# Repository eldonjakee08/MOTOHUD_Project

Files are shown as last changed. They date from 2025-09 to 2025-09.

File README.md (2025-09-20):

# MotoHUD Project
A proof of concept project that aims to integrate a heads-up display (HUD) into a motorcycle helmet, projecting real-time ECU sensor data such as speed, RPM, and engine load directly into the rider’s field of view.

This project aims to enhance riders situational awareness and safety by delivering vehicle metrics without requiring the rider to look away from the road.

# System Architecture & Overview


<br>**TRANSMITTER**
1. STM32WB5MMG MCU wakes up every 100ms to poll the motorcycle CAN bus for ECU sensor data.(e.g. Speed, RPM, Engine Load, etc.) 
2. Transmitter sends the ECU sensor data via BLE.
3. MCU goes into deep sleep state to conserve power. 

<br>**RECEIVER**
1. STM32WB5MMG MCU wakes up from deep sleep upon reception of sensor data from transmitter
2. MCU Parses the received data and displays into OLED screen.
3. Beamsplitter glass reflects the projection from OLED screen into the riders field of view
4. MCU returns into deep sleep state to conserve power.

# Project Milestones & Progress
1. Designed and fabricated a custom development board for STM32WB5MMG MCU.
2. Designed and fabricated custom module for LM3671 to power the receiver.
3. Designed the initial hardware for both Receiver and Transmitter.
4. Developed custom driver for SSD1315 OLED driver.
5. On-going development of custom driver for MCP2515 CAN controller

# Pending Tasks
1. Develop application firmware for both receiver and transmitter.
2. Fabricate the hardware for both receiver and transmitter.
3. Design and fabricate a receiver enclosure for optimal mounting into the helmet.
4. Design and fabricate an enclosure for the transmitter.

 # Future Improvements & Optimizations
 1. Optimize I2C and SPI data transmission using Direct Memory Access (DMA) to achieve higher throughput and lower power consumption.
 2. Design a load sharing protection circuit for the receiver’s battery to support simultaneous operation and charging.
 3. Music streaming feature via Bluetooth Low Energy (BLE).
 4. END VISION: Seamlessly stream live ECU sensor data into the helmets visor, delivering a real-time Augmented Reality (AR) experience.

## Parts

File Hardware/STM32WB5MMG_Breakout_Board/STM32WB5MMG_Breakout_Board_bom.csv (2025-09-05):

Comment | Designator | Footprint
100nF | C1 | Capacitor_SMD:C_0603_1608Metric
3.3pF | C2,C4 | Capacitor_SMD:C_0201_0603Metric
4.7uF | C5 | Capacitor_SMD:C_0603_1608Metric
Conn_01x15_Pin | J1,J4 | Connector_PinHeader_2.54mm:PinHeader_1x15_P2.54mm_Vertical
Conn_01x11_Pin | J2 | Connector_PinHeader_2.54mm:PinHeader_1x11_P2.54mm_Vertical
Conn_01x10_Pin | J3 | Connector_PinHeader_2.54mm:PinHeader_1x10_P2.54mm_Vertical
Conn_01x05_Pin | J5 | Connector_PinHeader_2.54mm:PinHeader_1x05_P2.54mm_Vertical
Conn_01x2_Pin | J6 | Connector_PinHeader_2.54mm:PinHeader_1x02_P2.54mm_Vertical
Conn_01x1_Pin | J7 | Connector_PinHeader_2.54mm:PinHeader_1x01_P2.54mm_Vertical
100 Ohms | R1 | Resistor_SMD:R_0201_0603Metric
STM32WB5MMG | U1 | RF_Module:ST-SiP-LGA-86-11x7.3mm

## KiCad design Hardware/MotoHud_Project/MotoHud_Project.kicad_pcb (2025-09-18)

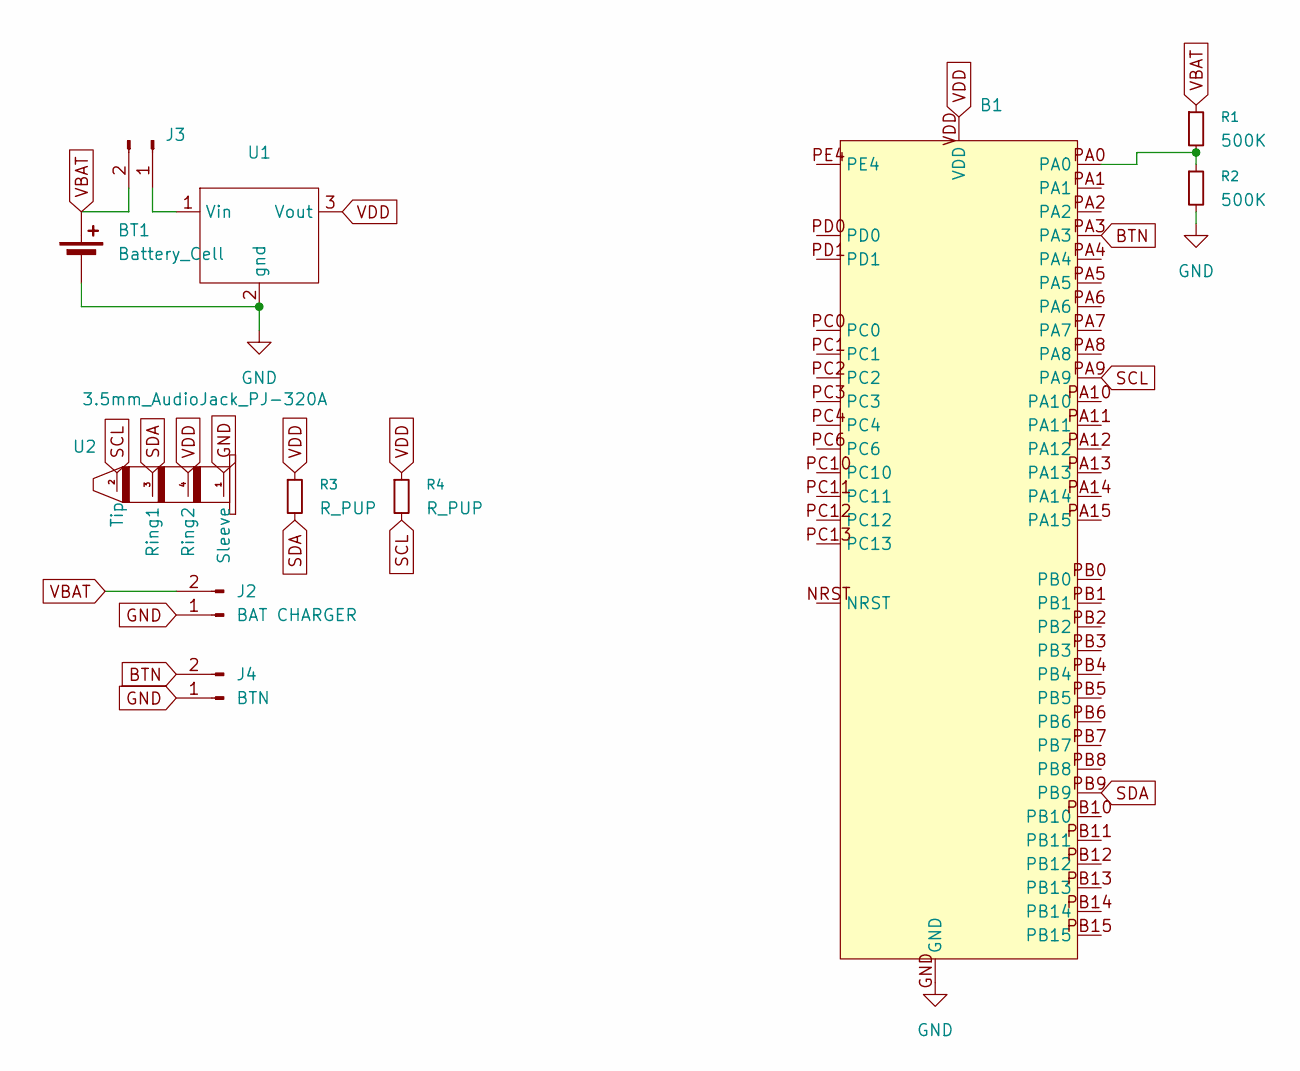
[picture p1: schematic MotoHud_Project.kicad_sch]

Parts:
B1: STM32WB5MMG_CUSTOM_DEVBOARD
BT1: Battery_Cell; PinHeader_1x02_P2.54mm_Vertical
J2: BAT CHARGER; PinHeader_1x02_P2.54mm_Vertical
J3: Conn_01x02_Pin; PinHeader_1x02_P2.54mm_Vertical
J4: BTN; PinHeader_1x02_P2.54mm_Vertical
R1, R2: 500K; R_0603_1608Metric_Pad0.98x0.95mm_HandSolder
R3, R4: R_PUP; R_Axial_DIN0207_L6.3mm_D2.5mm_P10.16mm_Horizontal
U1: LM3671_MODULE
U2: 3.5mm_AudioJack_PJ-320A; 3.5mm_AudioJack_PJ-320A_NoGuide

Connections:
BTN: B1.PA3, J4.2
GND: B1.GND, BT1.2 (-), J2.1, J4.1, R2.2, U1.2 (gnd), U2.1 (Sleeve)
unnamed: B1.PA0, R1.2, R2.1
unnamed: J3.1, U1.1 (Vin)
SCL: B1.PA9, R4.2, U2.2 (Tip)
SDA: B1.PB9, R3.2, U2.3 (Ring1)
VBAT: BT1.1 (+), J2.2, J3.2, R1.1
VDD: B1.VDD, R3.1, R4.1, U1.3 (Vout), U2.4 (Ring2)

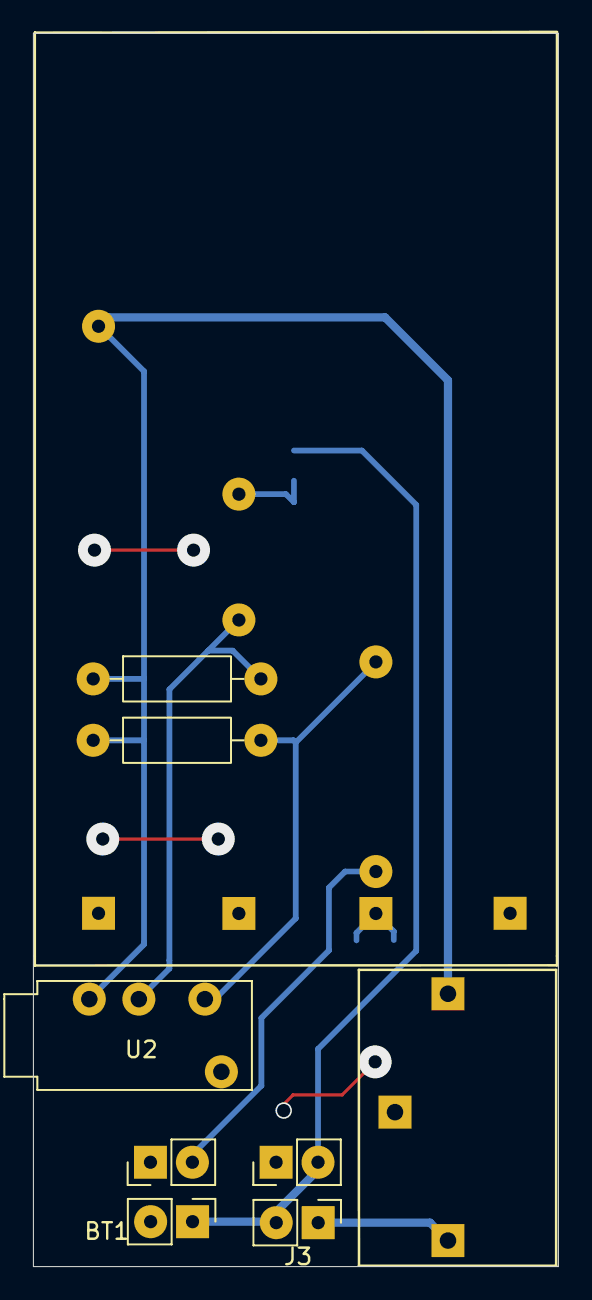
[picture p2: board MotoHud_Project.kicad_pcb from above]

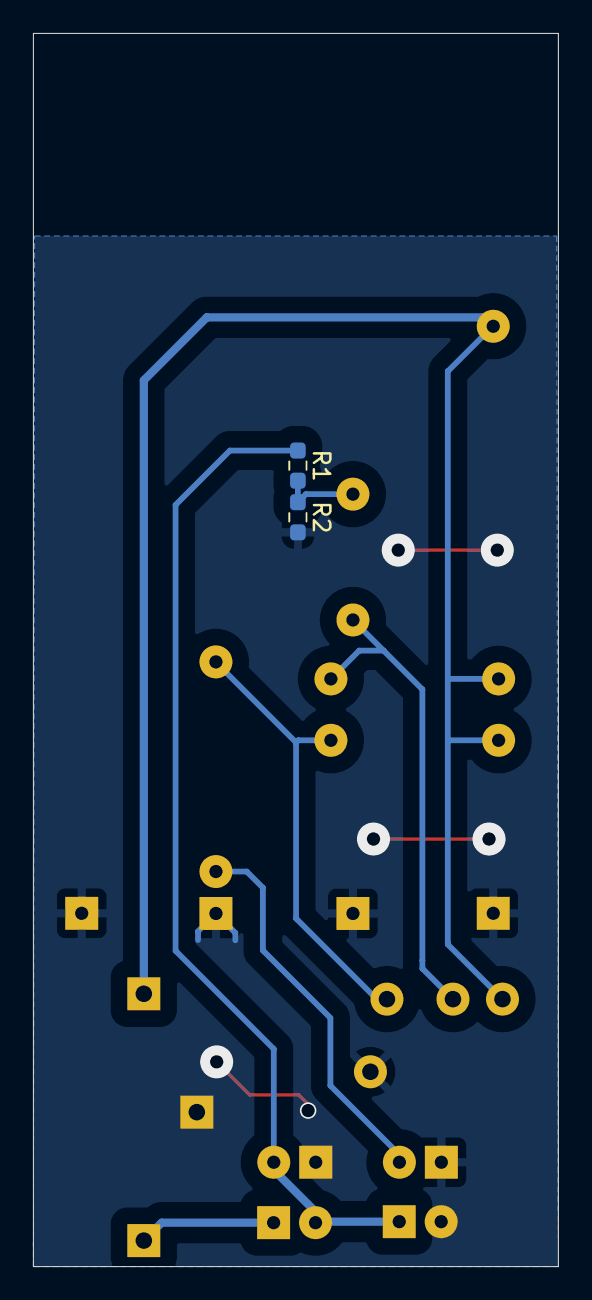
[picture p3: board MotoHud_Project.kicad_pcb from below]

Board: 2 copper layers, 31.8 x 74.7 mm, 11 parts (2 on the bottom side), 8 nets.

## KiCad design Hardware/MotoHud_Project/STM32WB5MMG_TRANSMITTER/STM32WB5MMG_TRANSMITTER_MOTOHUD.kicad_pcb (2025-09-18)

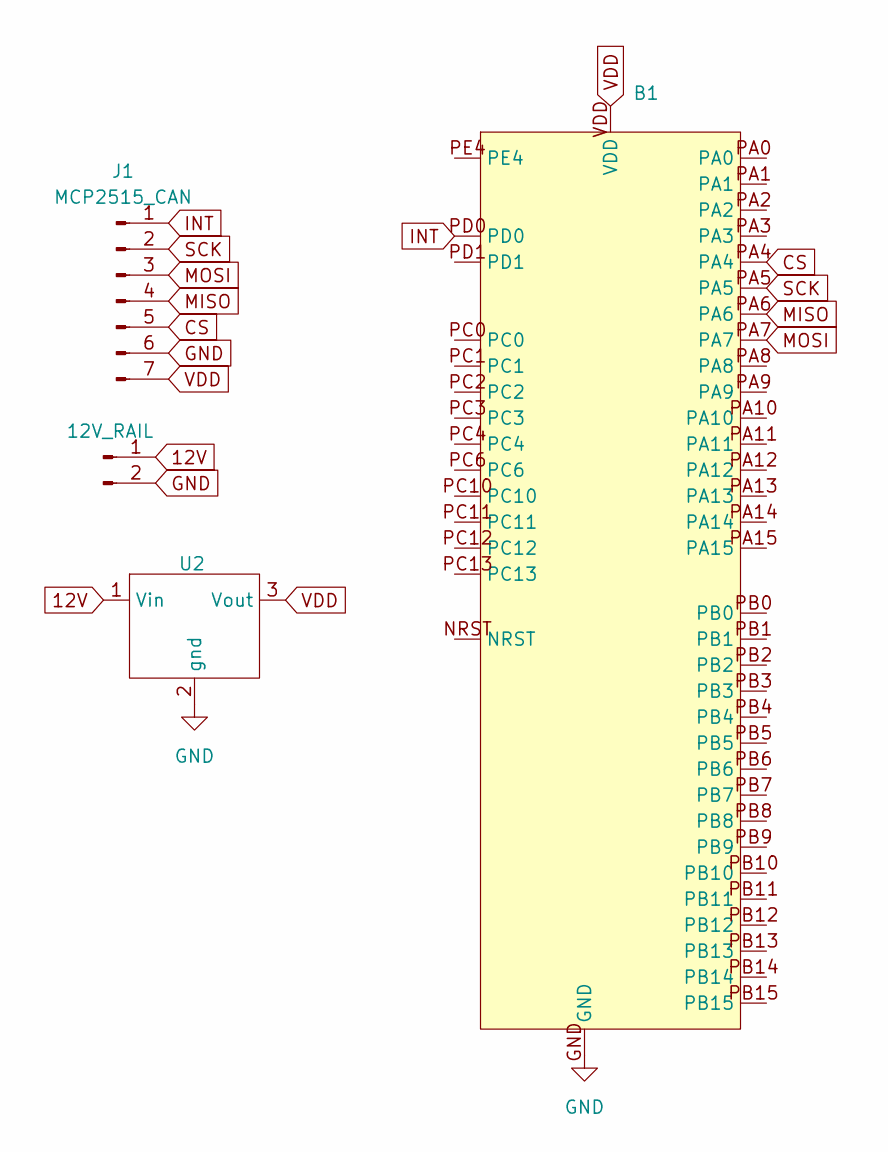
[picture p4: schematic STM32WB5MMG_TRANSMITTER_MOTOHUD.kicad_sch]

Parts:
B1: STM32WB5MMG_CUSTOM_DEVBOARD
J1: MCP2515_CAN; MCP2515_MODULE
J3: 12V_RAIL; PinHeader_1x02_P2.54mm_Vertical
U2: MP1584EN_DCtoDC_REGULATOR

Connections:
12V: J3.1, U2.1 (Vin)
CS: B1.PA4, J1.5
GND: B1.GND, J1.6, J3.2, U2.2 (gnd)
INT: B1.PD0, J1.1
MISO: B1.PA6, J1.4
MOSI: B1.PA7, J1.3
SCK: B1.PA5, J1.2
VDD: B1.VDD, J1.7, U2.3 (Vout)

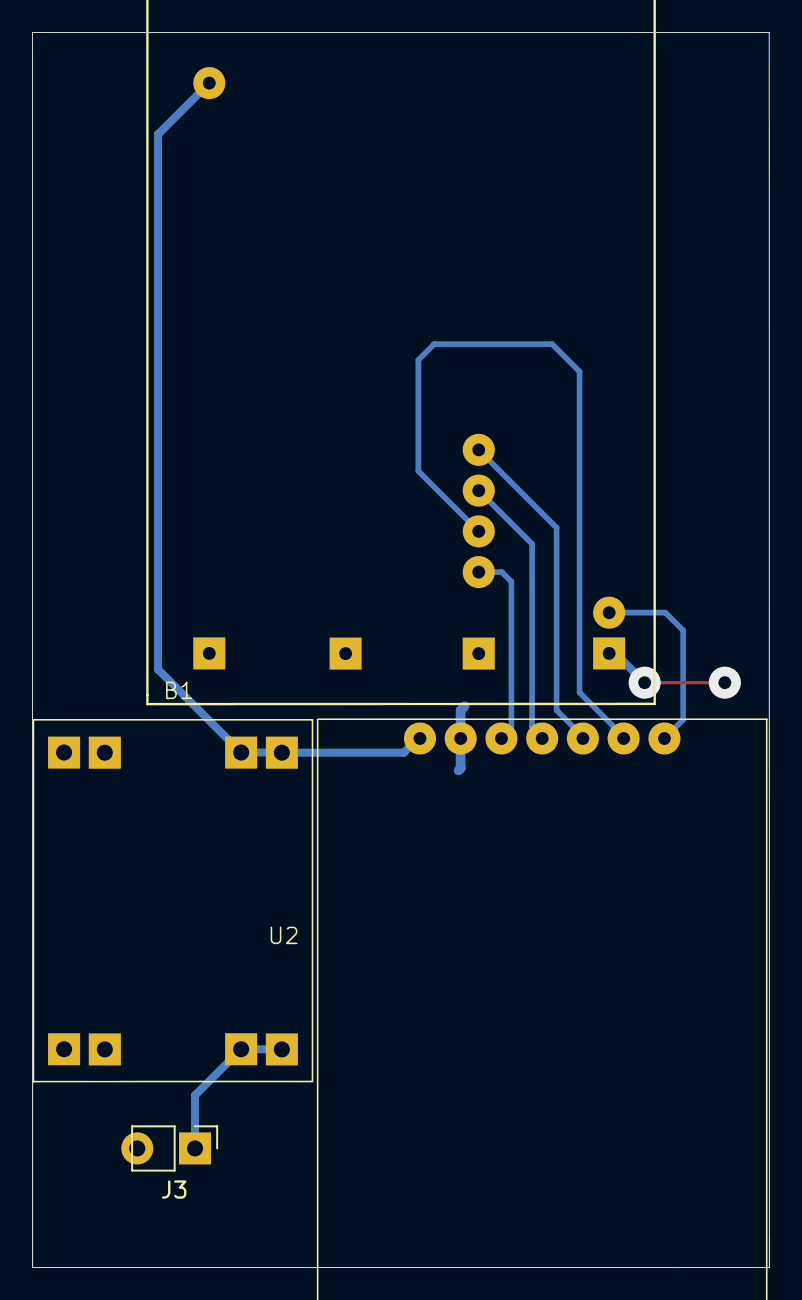
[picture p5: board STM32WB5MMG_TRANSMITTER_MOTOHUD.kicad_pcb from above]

Board: 2 copper layers, 46.0 x 77.0 mm, 4 parts (0 on the bottom side), 8 nets.

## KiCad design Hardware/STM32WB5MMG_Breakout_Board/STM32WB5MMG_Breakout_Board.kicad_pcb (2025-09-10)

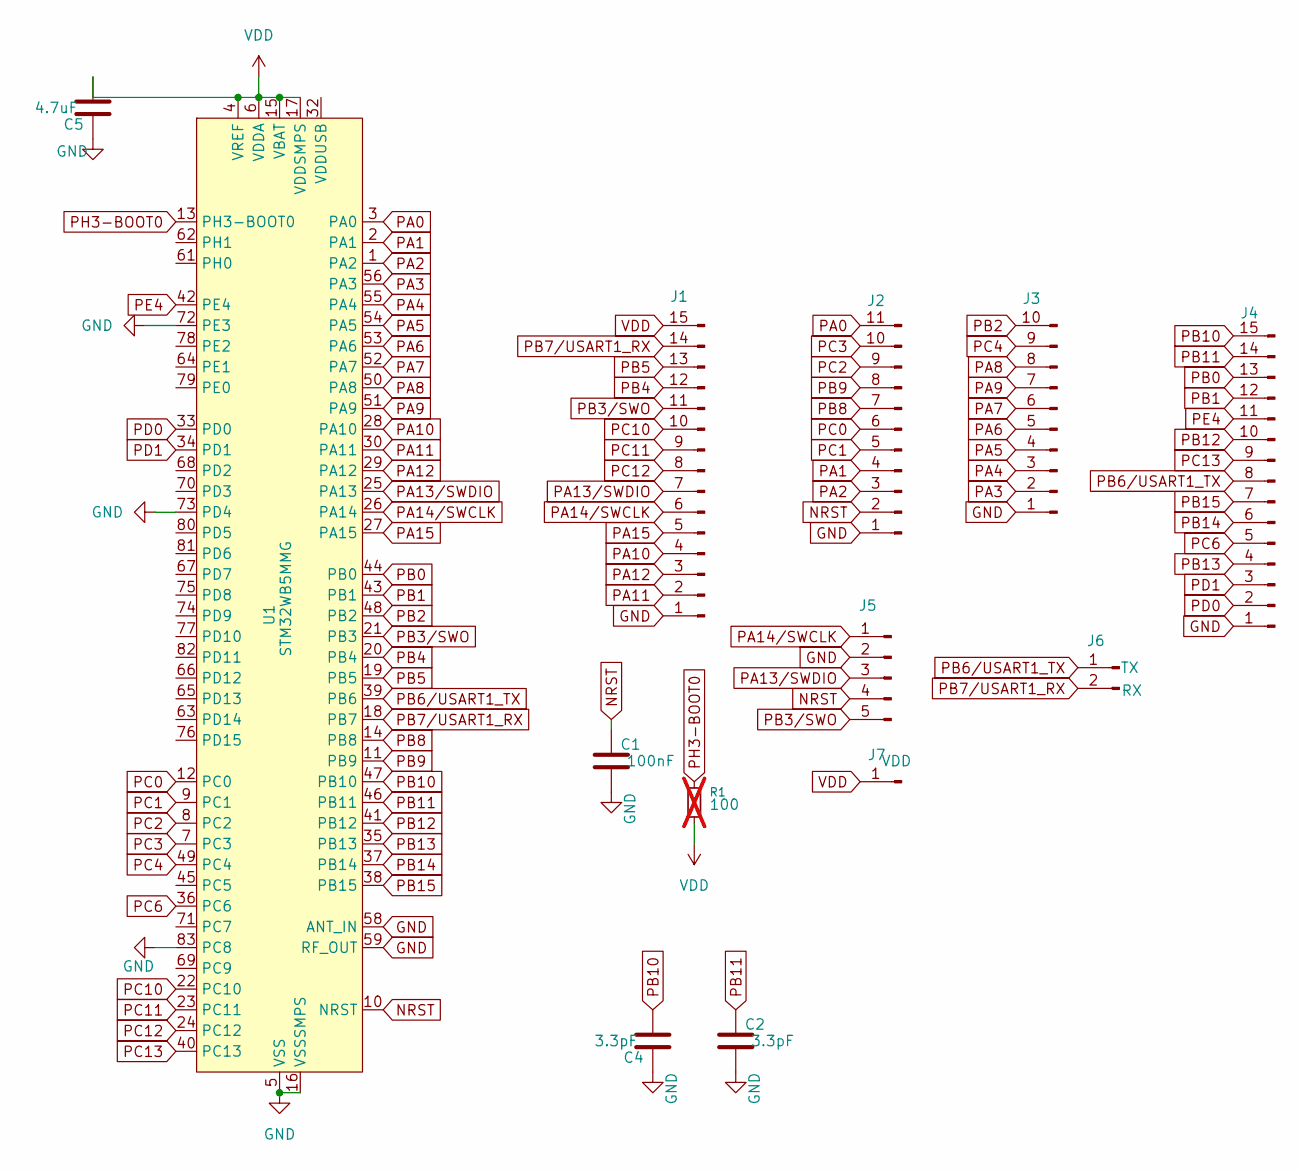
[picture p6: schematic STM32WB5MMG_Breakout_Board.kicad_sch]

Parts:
C1: 100nF; C_0603_1608Metric
C2, C4: 3.3pF; C_0201_0603Metric
C5: 4.7uF; C_0603_1608Metric
J1, J4: PinHeader_1x15_P2.54mm_Vertical
J2: Conn_01x11_Pin; PinHeader_1x11_P2.54mm_Vertical
J3: PinHeader_1x10_P2.54mm_Vertical
J5: PinHeader_1x05_P2.54mm_Vertical
J6: PinHeader_1x02_P2.54mm_Vertical
J7: VDD; PinHeader_1x01_P2.54mm_Vertical
R1: 100; R_0201_0603Metric; not fitted
U1: STM32WB5MMG; ST-SiP-LGA-86-11x7.3mm

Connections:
GND: C1.2, C2.2, C4.1, C5.1, J1.1, J2.1, J3.1, J4.1, J5.2, U1.5 (VSS), U1.16 (VSSSMPS), U1.31 (VSS), U1.57 (VSS), U1.58 (ANT_IN), U1.59 (RF_OUT), U1.60 (VSS), U1.72 (PE3), U1.73 (PD4), U1.83 (PC8), U1.84 (VSS), U1.86 (VSS)
NRST: C1.1, J2.2, J5.4, U1.10 (NRST)
PA0: J2.11, U1.3 (PA0)
PA1: J2.4, U1.2 (PA1)
PA2: J2.3, U1.1 (PA2)
PA3: J3.2, U1.56 (PA3)
PA4: J3.3, U1.55 (PA4)
PA5: J3.4, U1.54 (PA5)
PA6: J3.5, U1.53 (PA6)
PA7: J3.6, U1.52 (PA7)
PA8: J3.8, U1.50 (PA8)
PA9: J3.7, U1.51 (PA9)
PA10: J1.4, U1.28 (PA10)
PA11: J1.2, U1.30 (PA11)
PA12: J1.3, U1.29 (PA12)
PA13/SWDIO: J1.7, J5.3, U1.25 (PA13)
PA14/SWCLK: J1.6, J5.1, U1.26 (PA14)
PA15: J1.5, U1.27 (PA15)
PB0: J4.13, U1.44 (PB0)
PB1: J4.12, U1.43 (PB1)
PB2: J3.10, U1.48 (PB2)
PB3/SWO: J1.11, J5.5, U1.21 (PB3)
PB4: J1.12, U1.20 (PB4)
PB5: J1.13, U1.19 (PB5)
PB6/USART1_TX: J4.8, J6.1, U1.39 (PB6)
PB7/USART1_RX: J1.14, J6.2, U1.18 (PB7)
PB8: J2.7, U1.14 (PB8)
PB9: J2.8, U1.11 (PB9)
PB10: C4.2, J4.15, U1.47 (PB10)
PB11: C2.1, J4.14, U1.46 (PB11)
PB12: J4.10, U1.41 (PB12)
PB13: J4.4, U1.35 (PB13)
PB14: J4.6, U1.37 (PB14)
PB15: J4.7, U1.38 (PB15)
PC0: J2.6, U1.12 (PC0)
PC1: J2.5, U1.9 (PC1)
PC2: J2.9, U1.8 (PC2)
PC3: J2.10, U1.7 (PC3)
PC4: J3.9, U1.49 (PC4)
PC6: J4.5, U1.36 (PC6)
PC10: J1.10, U1.22 (PC10)
PC11: J1.9, U1.23 (PC11)
PC12: J1.8, U1.24 (PC12)
PC13: J4.9, U1.40 (PC13)
PD0: J4.2, U1.33 (PD0)
PD1: J4.3, U1.34 (PD1)
PE4: J4.11, U1.42 (PE4)
PH3-BOOT0: R1.1, U1.13 (PH3-BOOT0)
VDD: C5.2, J1.15, J7.1, R1.2, U1.4 (VREF), U1.6 (VDDA), U1.15 (VBAT), U1.17 (VDDSMPS)

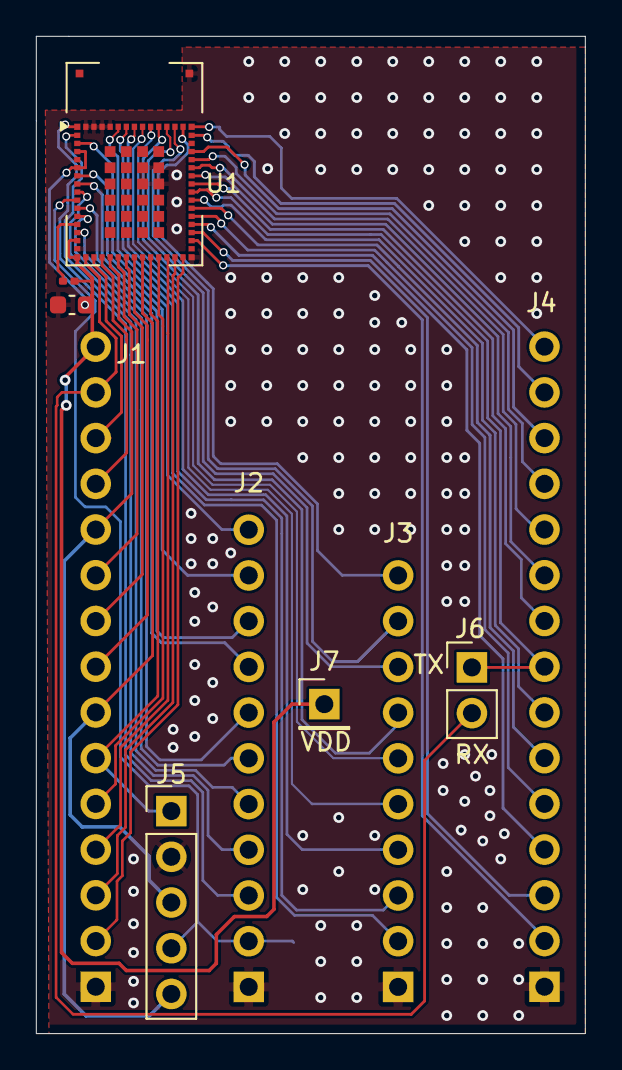
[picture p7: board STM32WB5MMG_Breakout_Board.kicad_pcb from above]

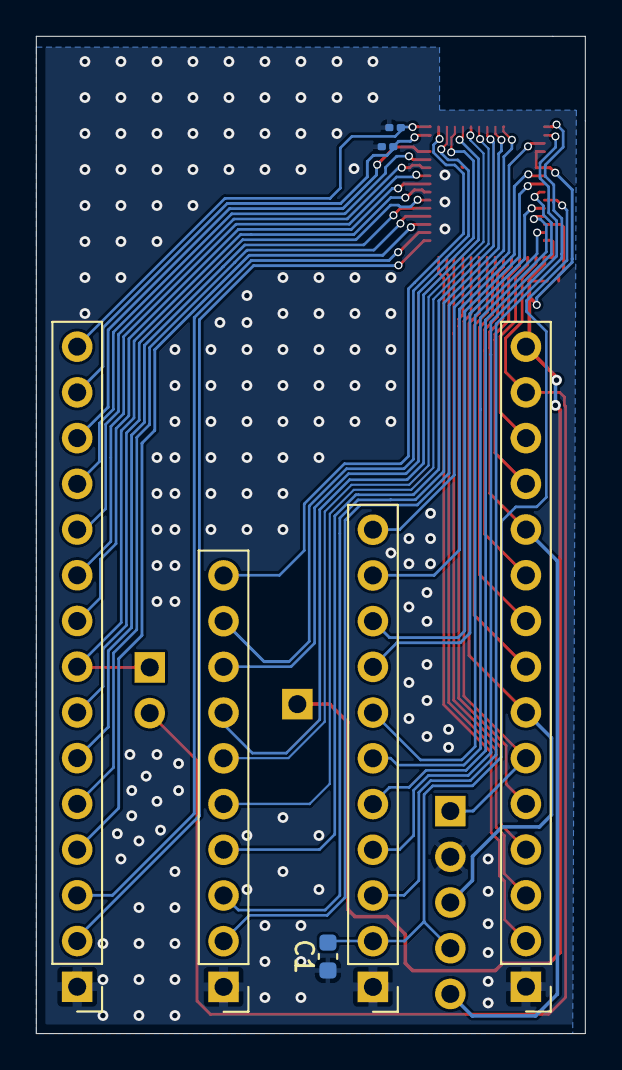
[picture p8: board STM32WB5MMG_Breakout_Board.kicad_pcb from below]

Board: 2 copper layers, 30.5 x 55.4 mm, 13 parts (7 on the bottom side), 49 nets.

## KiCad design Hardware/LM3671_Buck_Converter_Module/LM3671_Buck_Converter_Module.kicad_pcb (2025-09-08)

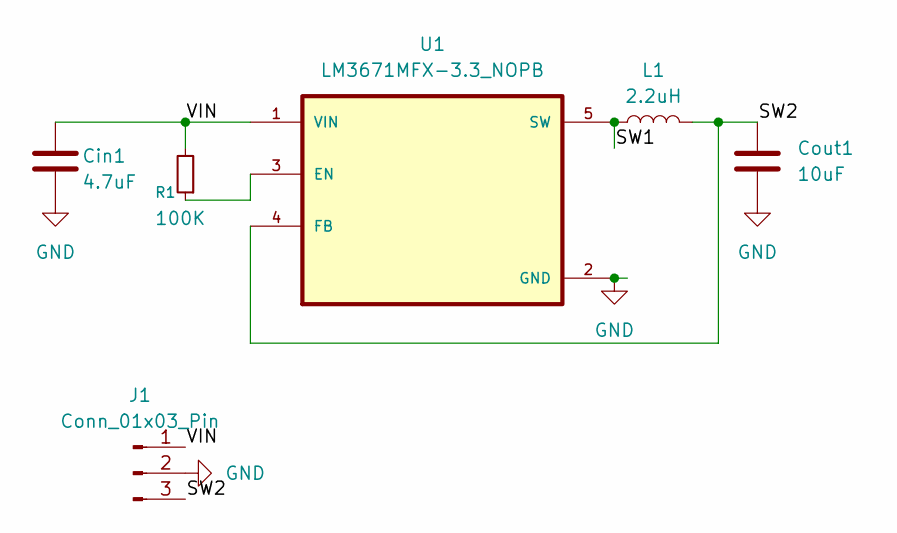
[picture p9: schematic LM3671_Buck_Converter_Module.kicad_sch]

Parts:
Cin1: 4.7uF; C_1206_3216Metric_Pad1.33x1.80mm_HandSolder
Cout1: 10uF; C_1206_3216Metric_Pad1.33x1.80mm_HandSolder
J1: Conn_01x03_Pin; PinHeader_1x03_P2.54mm_Vertical
L1: 2.2uH; 0806(2016 METRIC)_CIGT201610_SAM
R1: 100K; R_0603_1608Metric_Pad0.98x0.95mm_HandSolder
U1: LM3671MFX-3.3_NOPB; LM3671MFX-3.3_NOPB_SOT95P280X145-5N

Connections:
/SW1: L1.1, U1.5 (SW)
/SW2: Cout1.1, J1.3, L1.2, U1.4 (FB)
/VIN: Cin1.1, J1.1, R1.2, U1.1 (VIN)
GND: Cin1.2, Cout1.2, J1.2, U1.2 (GND)
unnamed: R1.1, U1.3 (EN)

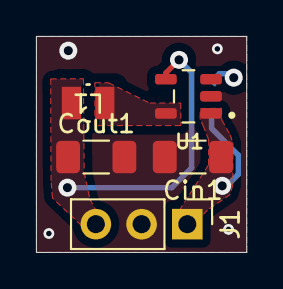
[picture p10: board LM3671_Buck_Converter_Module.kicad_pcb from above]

Board: 2 copper layers, 11.7 x 12.0 mm, 6 parts (1 on the bottom side), 5 nets.

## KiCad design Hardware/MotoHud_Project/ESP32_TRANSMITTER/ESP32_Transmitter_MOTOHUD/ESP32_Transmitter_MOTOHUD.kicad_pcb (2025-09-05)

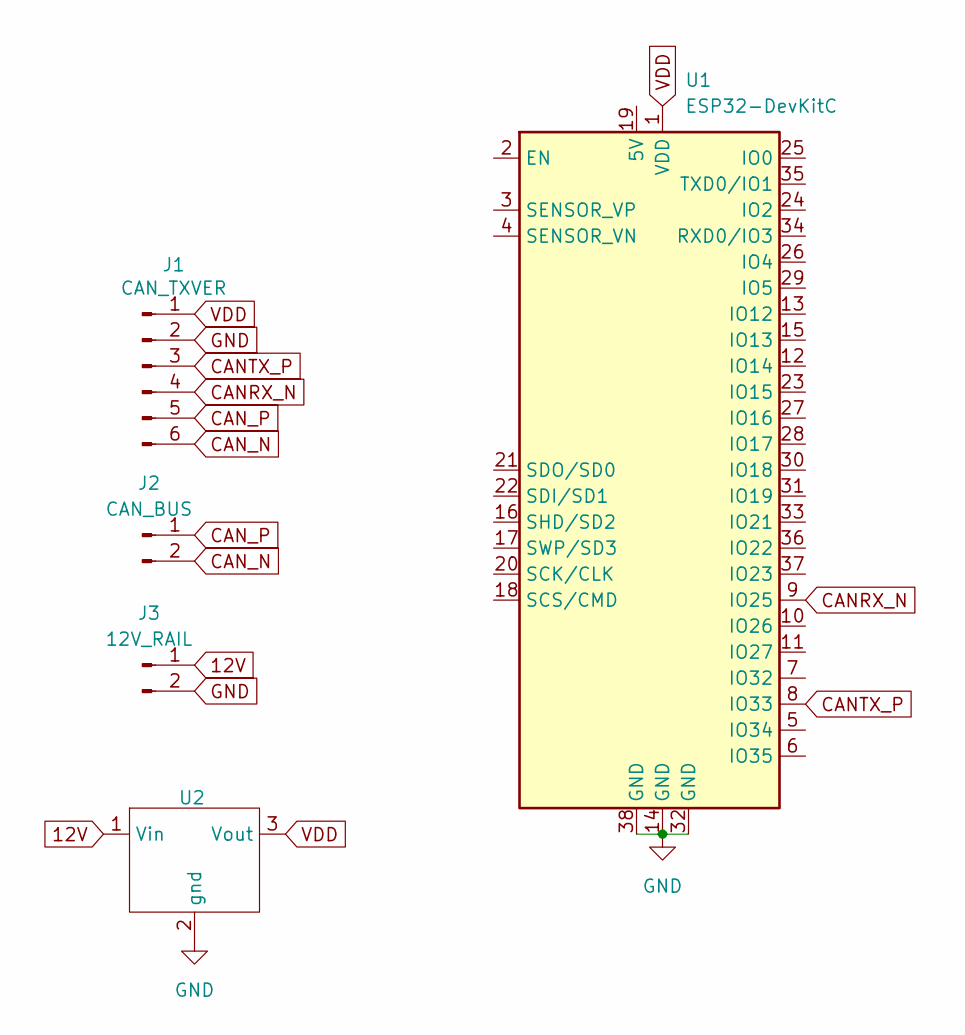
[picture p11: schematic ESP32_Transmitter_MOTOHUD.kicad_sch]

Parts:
J1: CAN_TXVER; PinHeader_1x06_P2.54mm_Vertical
J2: CAN_BUS; PinHeader_1x02_P2.54mm_Vertical
J3: 12V_RAIL; PinHeader_1x02_P2.54mm_Vertical
U1: ESP32-DevKitC
U2: MP1584EN_DCtoDC_REGULATOR

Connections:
12V: J3.1, U2.1 (Vin)
CANRX_N: J1.4, U1.9 (IO25)
CANTX_P: J1.3, U1.8 (IO33)
CAN_N: J1.6, J2.2
CAN_P: J1.5, J2.1
GND: J1.2, J3.2, U1.14 (GND), U1.32 (GND), U1.38 (GND), U2.2 (gnd)
VDD: J1.1, U1.1 (VDD), U2.3 (Vout)

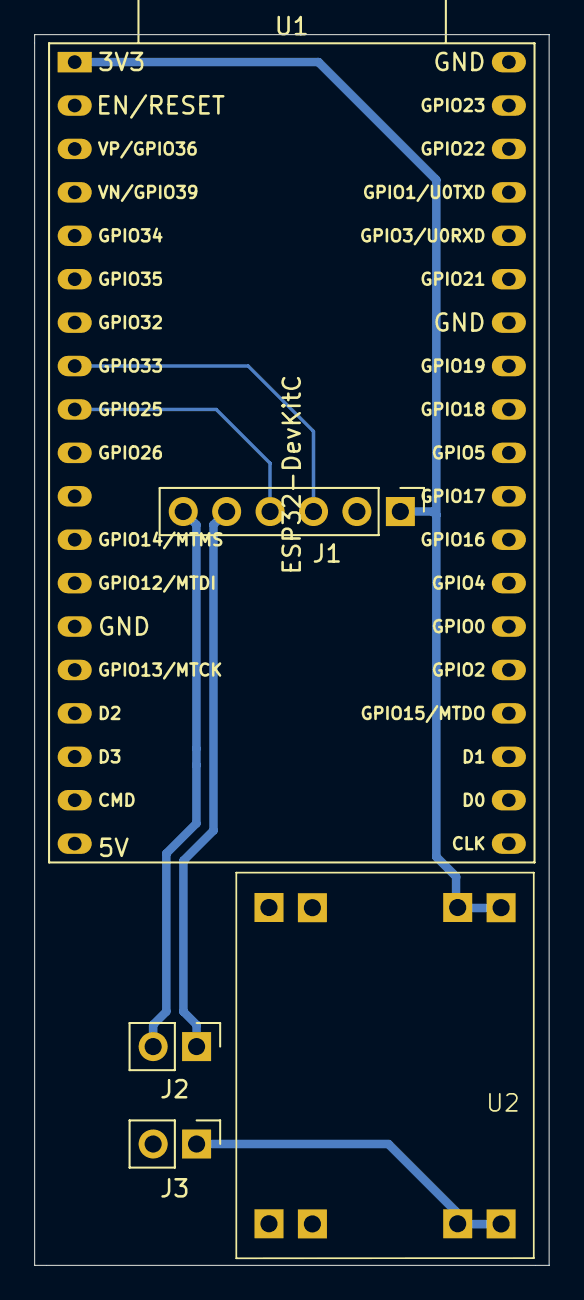
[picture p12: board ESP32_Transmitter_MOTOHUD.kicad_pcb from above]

Board: 2 copper layers, 30.1 x 72.0 mm, 5 parts (0 on the bottom side), 7 nets.

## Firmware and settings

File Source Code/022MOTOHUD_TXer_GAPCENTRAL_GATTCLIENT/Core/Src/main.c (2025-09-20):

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
/* Includes ------------------------------------------------------------------*/
#include "main.h"

/* USER CODE BEGIN Includes */
#include "mcp2515_driver.h"
/* USER CODE END Includes */

IPCC_HandleTypeDef hipcc;

RTC_HandleTypeDef hrtc;

SPI_HandleTypeDef hspi1;
DMA_HandleTypeDef hdma_spi1_rx;
DMA_HandleTypeDef hdma_spi1_tx;

/* USER CODE BEGIN PV */
MCP2515_CFG_Handle_t MCP2515_Handle;

/* USER CODE END PV */

void SystemClock_Config(void);
void PeriphCommonClock_Config(void);
static void MX_GPIO_Init(void);
static void MX_DMA_Init(void);
static void MX_IPCC_Init(void);
static void MX_RTC_Init(void);
static void MX_SPI1_Init(void);
/* USER CODE BEGIN PFP */
static void MCP2515_Init2(void);
/* USER CODE END PFP */

/* USER CODE BEGIN 0 */
uint8_t DataBuffer[8] = {0x40, 0x40,0x40, 0x40, 0x40, 0X09, 0X09, 0X09};

/* USER CODE END 0 */

/**
 * @brief  The application entry point.
 * @retval int
 */
int main(void)
{

	/* MCU Configuration--------------------------------------------------------*/

	/* Reset of all peripherals, Initializes the Flash interface and the Systick. */
	HAL_Init();

	/* Configure the system clock */
	SystemClock_Config();

	/* Configure the peripherals common clocks */
	PeriphCommonClock_Config();

	/* IPCC initialisation */
	MX_IPCC_Init();

	/* Initialize all configured peripherals */
	MX_GPIO_Init();
	MX_DMA_Init();
	MX_RTC_Init();
	MX_SPI1_Init();
	/* USER CODE BEGIN 2 */
	MCP2515_Init2();

	MCP2515_CAN_Transmit_Single_TxBuffer(SEND_TxBUFFER1, 0x7E8, DataBuffer, 5);

	/* USER CODE END 2 */

	/* Infinite loop */
	/* USER CODE BEGIN WHILE */
	while (1)
	{
		/* USER CODE END WHILE */

		/* USER CODE BEGIN 3 */
	}
	/* USER CODE END 3 */
}

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
/* USER CODE BEGIN 4 */
static void MCP2515_Init2(void){
	MCP2515_Handle.RxBUFFERn_FILT_CFG = RxBUFFER0_FILT_CFG_MASK | RxBUFFER1_FILT_CFG_MASK;

	MCP2515_Handle.RxBuffer0_FILT.RxBuffer0_AcceptMask = 0x7F8;	//RxBuffer0 Mask
	MCP2515_Handle.RxBuffer0_FILT.RxBuffer0_Filt[0] = 0x7E8; 	//Filter 0
	MCP2515_Handle.RxBuffer0_FILT.RxBuffer0_Filt[1] = 0x7EF; 	//Filter 1

	MCP2515_Handle.RxBuffer1_FILT.RxBuffer1_AcceptMask = 0x7F8;	//RxBuffer1 Mask
	MCP2515_Handle.RxBuffer1_FILT.RxBuffer1_Filt[0] = 0x7E8; 	//Filter 2
	MCP2515_Handle.RxBuffer1_FILT.RxBuffer1_Filt[1] = 0x7E8; 	//Filter 3
	MCP2515_Handle.RxBuffer1_FILT.RxBuffer1_Filt[2] = 0x7EF; 	//Filter 4
	MCP2515_Handle.RxBuffer1_FILT.RxBuffer1_Filt[3] = 0x7EF; 	//Filter 5

	MCP2515_Handle.CAN_Baud_PreScaler = 0;
	MCP2515_Handle.CAN_Speed_Kbps = CAN_SPEED_500Kbps;
	MCP2515_Handle.MCP2515_Osc = 8000000;
	MCP2515_Handle.PH1_Seg_TQ_Length = PHASEn_SEG_LEN_3TQ;
	MCP2515_Handle.PH2_Seg_TQ_Length = PHASEn_SEG_LEN_3TQ;
	MCP2515_Handle.ProgDelay_TQ_Length = PROG_DELAY_SEG_LEN_1TQ;
	MCP2515_Handle.SJW_TQ_Length = SJW_LEN_1TQ;

	MCP2515_Handle.INT_Enable_Mask = RxBUFFER0_FULL_IE | RxBUFFER1_FULL_IE;

	MCP2515_Init(&MCP2515_Handle);
}

/* USER CODE END 4 */
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


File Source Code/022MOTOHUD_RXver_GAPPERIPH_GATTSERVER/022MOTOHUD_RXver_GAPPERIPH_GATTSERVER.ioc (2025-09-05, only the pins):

Mcu.UserName=STM32WB5MMGHx
PA0.Signal=ADCx_IN5
PA3.GPIO_Label=USR_BTN1
PA3.Signal=GPIO_Input
PA9.Signal=I2C1_SCL
PB6.Signal=USART1_TX
PB7.Signal=USART1_RX
PB9.Signal=I2C1_SDA
PC2.Signal=GPIO_Output

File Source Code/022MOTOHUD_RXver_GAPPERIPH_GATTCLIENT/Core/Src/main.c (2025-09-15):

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
/* Includes ------------------------------------------------------------------*/
#include "main.h"

/* USER CODE BEGIN Includes */
extern uint8_t yong2_bitmap[1024];
extern uint8_t center_bitmap[1024];
/* USER CODE END Includes */

ADC_HandleTypeDef hadc1;

I2C_HandleTypeDef hi2c1;

IPCC_HandleTypeDef hipcc;

RTC_HandleTypeDef hrtc;

UART_HandleTypeDef huart1;

void SystemClock_Config(void);
void PeriphCommonClock_Config(void);
static void MX_GPIO_Init(void);
static void MX_IPCC_Init(void);
static void MX_RTC_Init(void);
static void MX_ADC1_Init(void);
static void MX_I2C1_Init(void);
static void MX_RF_Init(void);
/**
 * @brief  The application entry point.
 * @retval int
 */
int main(void)
{

	/* MCU Configuration--------------------------------------------------------*/

	/* Reset of all peripherals, Initializes the Flash interface and the Systick. */
	HAL_Init();
	/* Config code for STM32_WPAN (HSE Tuning must be done before system clock configuration) */
	MX_APPE_Config();

	/* Configure the system clock */
	SystemClock_Config();

	/* Configure the peripherals common clocks */
	PeriphCommonClock_Config();

	/* IPCC initialisation */
	MX_IPCC_Init();

	/* Initialize all configured peripherals */
	MX_GPIO_Init();
	MX_RTC_Init();
	MX_ADC1_Init();
	MX_I2C1_Init();
	MX_RF_Init();
	/* Init code for STM32_WPAN */
	MX_APPE_Init();

	/* Infinite loop */
	/* USER CODE BEGIN WHILE */
	//initialize OLED before calling any OLED functions
	oled_init();

	//speedometer digit test
	oled_RenderGlyph(&speedometer_digit_1, GLYPH_DIGIT_6, GLYPH_MODE_OVERWRITE);
	oled_RenderGlyph(&speedometer_digit_2, GLYPH_DIGIT_2, GLYPH_MODE_OVERWRITE);
	oled_RenderGlyph(&speedometer_digit_3, GLYPH_DIGIT_1, GLYPH_MODE_OVERWRITE);

	//rpm font test
	oled_RenderGlyph(&rpm_integer_digit_1, GLYPH_DIGIT_4, GLYPH_MODE_OVERWRITE);
	oled_RenderGlyph(&rpm_decimal_digit_2, GLYPH_DIGIT_5, GLYPH_MODE_OVERWRITE);

	//clock font test
	oled_RenderGlyph(&time_hour_digit_1, GLYPH_DIGIT_2, GLYPH_MODE_OVERWRITE);
	oled_RenderGlyph(&time_hour_digit_2, GLYPH_DIGIT_3, GLYPH_MODE_OVERWRITE);
	oled_RenderGlyph(&time_minute_digit_1, GLYPH_DIGIT_5, GLYPH_MODE_OVERWRITE);
	oled_RenderGlyph(&time_minute_digit_2, GLYPH_DIGIT_4, GLYPH_MODE_OVERWRITE);

	//battery voltage font test
	oled_RenderGlyph(&battery_integer_digit_1, GLYPH_DIGIT_3, GLYPH_MODE_OVERWRITE);
	oled_RenderGlyph(&battery_decimal_digit_1, GLYPH_DIGIT_6, GLYPH_MODE_OVERWRITE);
	oled_RenderGlyph(&battery_V_char, GLYPH_V_CHAR, GLYPH_MODE_OVERWRITE);

	oled_UpdateScreen();

	uint8_t rpm_index = 0, fuel_index = 0, digit_index =0;;
	while (1)
	{
		/* USER CODE END WHILE */
		MX_APPE_Process();

		/* USER CODE BEGIN 3 */
		HAL_GPIO_WritePin(GPIOC, GPIO_PIN_2, SET);

		oled_RenderGlyph(&bluetooth_broadcasting_icon, GLYPH_SINGLE_ELEMENT, GLYPH_MODE_TOGGLE);
		oled_RenderGlyph(&left_turn_signal, GLYPH_SINGLE_ELEMENT, GLYPH_MODE_TOGGLE);
		oled_RenderGlyph(&right_turn_signal, GLYPH_SINGLE_ELEMENT, GLYPH_MODE_TOGGLE);

		//clock font test
		oled_RenderGlyph(&time_hour_digit_1, digit_index, GLYPH_MODE_OVERWRITE);
		oled_RenderGlyph(&time_hour_digit_2, digit_index, GLYPH_MODE_OVERWRITE);
		oled_RenderGlyph(&time_minute_digit_1, digit_index, GLYPH_MODE_OVERWRITE);
		oled_RenderGlyph(&time_minute_digit_2, digit_index, GLYPH_MODE_OVERWRITE);

		//battery voltage font test
		oled_RenderGlyph(&battery_integer_digit_1, digit_index, GLYPH_MODE_OVERWRITE);
		oled_RenderGlyph(&battery_decimal_digit_1, digit_index, GLYPH_MODE_OVERWRITE);

		//test drawing rpm gauge glyph
		oled_RenderGlyph(&rpm_bar_gauge, rpm_index, GLYPH_MODE_OVERWRITE);
		oled_RenderGlyph(&rpm_integer_digit_1, digit_index, GLYPH_MODE_OVERWRITE);
		oled_RenderGlyph(&rpm_decimal_digit_2, digit_index, GLYPH_MODE_OVERWRITE);

		//test drawing fuel gauge glyph
		oled_RenderGlyph(&fuel_bar_gauge, fuel_index, GLYPH_MODE_OVERWRITE);

		oled_RenderGlyph(&speedometer_digit_1, digit_index, GLYPH_MODE_OVERWRITE);
		oled_RenderGlyph(&speedometer_digit_2, digit_index, GLYPH_MODE_OVERWRITE);
		oled_RenderGlyph(&speedometer_digit_3, digit_index, GLYPH_MODE_OVERWRITE);
		HAL_GPIO_WritePin(GPIOC, GPIO_PIN_2, RESET);

		oled_UpdateScreen();

		rpm_index++;
		fuel_index++;
		digit_index++;

		if(rpm_index > GLYPH_GAUGE_LEVEL_15) rpm_index = 0;
		if(fuel_index > GLYPH_GAUGE_LEVEL_6) fuel_index = 0;
		if(digit_index > GLYPH_DIGIT_9) digit_index = 0;

		HAL_Delay(100);

	}
	/* USER CODE END 3 */
}

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


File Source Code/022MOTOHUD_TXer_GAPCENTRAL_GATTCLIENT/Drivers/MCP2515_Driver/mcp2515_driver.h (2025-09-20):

/*
 * mcp2515_driver.h
 *
 *  Created on: Sep 10, 2025
 *      Author: eldon
 */

#ifndef MCP2515_DRIVER_MCP2515_DRIVER_H_
#define MCP2515_DRIVER_MCP2515_DRIVER_H_

#include <stdint.h>
#include <string.h>
#include "stm32wbxx_hal.h"	//HAL library for STM32WBxx series, Replace with your STM32 series HAL library

//SPI CS (Slave Select)  and INT pin defines
#define CAN_INT_Pin GPIO_PIN_0
#define CAN_INT_GPIO_Port GPIOD
#define CAN_INT_EXTI_IRQn EXTI0_IRQn
#define SPI1_CS_Pin GPIO_PIN_4
#define SPI1_CS_GPIO_Port GPIOA

#define MAX_ADDRESS 	0x7D //Maximum register address

//dummy byte for clocking out slave data during reception
#define dummy_byte 		0x00

#define MCP2515_INTERNAL_CLK_FREQ	8000000 //in Hz. MCP2515 module installed oscillator, modify based on your installed oscillator on module

extern SPI_HandleTypeDef hspi1; 	//extern SPI handle

typedef enum{
	TXBUFFER_BUSY 			= 0x40,
	TX_SUCCESS	 			= 0x41,
	ERR_ARBITRATION_LOSS	= 0x42,
	ERR_TRANSMISSION		= 0x43,
	ERR_INVALID_INPUT		= 0x44
}CAN_Tx_Status_t;

//@SPI_Commands_t
typedef enum{
	SPI_COMMAND_RESET 			= 0xC0,
	SPI_COMMAND_READ 			= 0x03,
	SPI_COMMAND_READ_RX_BUFFER 	= 0x90,
	SPI_COMMAND_WRITEREGISTER 	= 0x02,
	SPI_COMMAND_LOAD_TX_BUFFER 	= 0x40,
	SPI_COMMAND_RTS 			= 0x80,
	SPI_COMMAND_READ_STATUS 	= 0xA0,
	SPI_COMMAND_RX_STATUS 		= 0xB0,
	SPI_COMMAND_BIT_MODIFY 		= 0x05
}SPI_Commands_t;


//@Read_RxBufferLoc_t
typedef enum{
	START_RXB0SIDH  = SPI_COMMAND_READ_RX_BUFFER | 0x00, //Receive Buffer 0, start at RXB0SIDH (Receive Buffer 0 Data Byte 0 Register: 0x61 Address)
	START_RXB0D0 	= SPI_COMMAND_READ_RX_BUFFER | 0X02, //Receive Buffer 0, start at RXB0D0 (Receive Buffer 0 Data Byte 0 Register: 0x66 Address)
	START_RXB1SIDH	= SPI_COMMAND_READ_RX_BUFFER | 0X04, //Receive Buffer 1, start at RXB1SIDH (Receive Buffer 1 Standard Identifier High Register: 0x71 Address)
	START_RXB1D0	= SPI_COMMAND_READ_RX_BUFFER | 0x06	 //Receive Buffer 1, start at RXB1D0 (Receive Buffer 1 Data Byte 0 Register: 0x76 Address)
}Read_RxBufferLoc_t;


//@Load_TxBufferLoc_t
typedef enum{
	START_TXB0SIDH	= SPI_COMMAND_LOAD_TX_BUFFER | 0X00, //TX Buffer 0, Start at TXB0SIDH (Transmit Buffer 0 Standard Identifier High Register: 0x31 Address)
	START_TXB0D0	= SPI_COMMAND_LOAD_TX_BUFFER | 0X01, //TX Buffer 0, Start at TXB0D0 (Transmit Buffer 0 Data Byte 0 Register: 0x36 Address)
	START_TXB1SIDH	= SPI_COMMAND_LOAD_TX_BUFFER | 0X02, //TX Buffer 1, Start at TXB1SIDH (Transmit Buffer 1 Standard Identifier High Register: 0x41 Address)
	START_TXB1D0	= SPI_COMMAND_LOAD_TX_BUFFER | 0X03, //TX Buffer 1, Start at TXB1D0 (Transmit Buffer 1 Data Byte 0 Register: 0x46 Address)
	START_TXB2SIDH	= SPI_COMMAND_LOAD_TX_BUFFER | 0X04, //TX Buffer 2, Start at TXB2SIDH (Transmit Buffer 2 Standard Identifier High Register: 0x51 Address)
	START_TXB2D0	= SPI_COMMAND_LOAD_TX_BUFFER | 0X05  //TX Buffer 2, Start at TXB2D0 (Transmit Buffer 2 Data Byte 0 Register: 0x56 Address)
}Load_TxBufferLoc_t;


//@RTS_TxBuffer_t
typedef enum{
	RTS_TxBUFFER0				= SPI_COMMAND_RTS | 0X01, //Request to Send for TX Buffer 0
	RTS_TxBUFFER1				= SPI_COMMAND_RTS | 0X02, //Request to Send for TX Buffer 1
	RTS_TxBUFFER2				= SPI_COMMAND_RTS | 0X04, //Request to Send for TX Buffer 2
	RTS_TxBUFFER0_TxBUFFER1		= SPI_COMMAND_RTS | 0X03, //Request to Send for TX Buffers 0 and 1
	RTS_TxBUFFER0_TxBUFFER2		= SPI_COMMAND_RTS | 0X05, //Request to Send for TX Buffers 0 and 2
	RTS_TxBUFFER1_TxBUFFER2		= SPI_COMMAND_RTS | 0X06, //Request to Send for TX Buffers 1 and 2
	RTS_ALL						= SPI_COMMAND_RTS | 0X07  //Request to Send for All TX Buffers
}RTS_TxBuffer_t;


//Structure for storing RxBuffer0 filter values. Does not support Extended CAN frame identifiers.
typedef struct{
	uint16_t  	RxBuffer0_Filt[2];		//RxBuffer0 Standard 11-bit Identifier Filter 0 to Filter 1
	uint16_t  	RxBuffer0_AcceptMask;	//RxBuffer0 Standard 11-bit Identifier Acceptance Mask
}RxBuffer0_Filter_Val_t;


//Structure for storing RxBuffer1 filter values. Does not support Extended CAN frame identifiers.
typedef struct{
	uint16_t  	RxBuffer1_Filt[4];		//RxBuffer1 Standard 11-bit Identifier Filter 2 to Filter 5
	uint16_t  	RxBuffer1_AcceptMask;	//RxBuffer1 Standard 11-bit Identifier Acceptance Mask
}RxBuffer1_Filter_Val_t;


//contains user defined configurations for MCP2515
typedef struct{
	//Filter Configuration Parameters
	uint8_t RxBUFFERn_FILT_CFG;						//Specifies which RxBuffer filters to configure. Ref @RxBuffer_Filt_CFG
	RxBuffer0_Filter_Val_t RxBuffer0_FILT;			//Input 11-bit Standard Identifier filters for RxBuffer0
	RxBuffer1_Filter_Val_t RxBuffer1_FILT;			//Input 11-bit Standard Identifier filters for RxBuffer1

	//CAN Bus timing configuration parameters
	uint8_t CAN_Baud_PreScaler;		//CNF1: BRP[5:0] Baud Rate Prescaler bits. Values 0 to 63
	uint8_t ProgDelay_TQ_Length;	//Propagation Delay length in Time Quanta. Ref @Propagation_Delay_Segment_Length
	uint8_t PH1_Seg_TQ_Length;		//Phase 1 Segment length in Time Quanta. Ref @PHASEn_Segment_Length
	uint8_t PH2_Seg_TQ_Length;		//Phase 2 Segment length in Time Quanta. Ref @PHASEn_Segment_Length
	uint8_t SJW_TQ_Length;			//Synchronization Jump Width in Time Quanta. Ref @Synchronization_Jump_Width_Length
	uint32_t CAN_Speed_Kbps;		//Input desired CAN bus speed in Hz. Ref @CAN_Speed_CFG
	uint32_t MCP2515_Osc; 			//Input oscillator frequency in Hz installed on your MCP2515 module/hardware

	//Interrupt Configuration Parameters
	uint8_t INT_Enable_Mask;		//Specifies which interrupt events are to be enabled. Ref @Interrupt_Enable_Bits
}MCP2515_CFG_Handle_t;


/**********************MCP2515 REGISTER ADDRESSES*******************/
//@register_address
/*****Acceptance Filter Registers*****/
//Receive Buffer0 Filters
//TODO: input shorthand notation of register name in comments
#define RxBUFFER0_FILTER0_SIDH_REG_ADDR     0x00 //Filter 0 Standard Identifier High Register
#define RxBUFFER0_FILTER0_SIDL_REG_ADDR     0x01 //Filter 0 Standard Identifier Low Register
#define RxBUFFER0_FILTER0_EID8_REG_ADDR  	0x02 //Filter 0 Extended Identifier High Register
#define RxBUFFER0_FILTER0_EID0_REG_ADDR     0x03 //Filter 0 Extended Identifier Low Register
#define RxBUFFER0_FILTER1_SIDH_REG_ADDR    	0x04 //Filter 1 Standard Identifier High Register
#define RxBUFFER0_FILTER1_SIDL_REG_ADDR    	0x05 //Filter 1 Standard Identifier Low Register
#define RxBUFFER0_FILTER1_EID8_REG_ADDR    	0x06 //Filter 1 Extended Identifier High Register
#define RxBUFFER0_FILTER1_EID0_REG_ADDR    	0x07 //Filter 1 Extended Identifier Low Register
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

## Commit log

2025-09-05 added project files
    [ESP32_Transmitter_MOTOHUD.kicad_pcb, ESP32_Transmitter_MOTOHUD.kicad_sch, LM3671_Buck_Converter_Module.kicad_pcb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]
2025-09-08 updated rxver and txver hardware
    [LM3671_Buck_Converter_Module.kicad_pcb, LM3671_Buck_Converter_Module.kicad_sch, MotoHud_Project.kicad_pcb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]
2025-09-10 updated stm32wb5mmg breakout board hardware
    [STM32WB5MMG_Breakout_Board.kicad_pcb]
2025-09-18 updated hardware
    [MotoHud_Project.kicad_pcb, MotoHud_Project.kicad_sch, STM32WB5MMG_TRANSMITTER_MOTOHUD.kicad_pcb]

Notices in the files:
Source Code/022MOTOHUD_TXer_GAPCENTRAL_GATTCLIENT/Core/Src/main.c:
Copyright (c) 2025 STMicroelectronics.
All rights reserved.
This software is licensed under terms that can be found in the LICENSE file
